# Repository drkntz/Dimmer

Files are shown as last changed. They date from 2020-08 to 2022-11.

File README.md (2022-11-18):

# Dimmer
A peripheral for microprocessor control of 120V AC.

This project originally started in 2020 as a proof of concept for an AC motor controller, but can be used for many projects involving variable duty cycle AC control. It supports operation for low current (<5A) AC driving as a low-side switch. 

The original board included both an AC triac control and a 5V non-isolated power supply (linkswitch LNK3206). This unit was meant for use in situations where the device is fully enclosed in an insulated housing. However, if fully isolated operation is desired, the Dimmer may be used with an external 5V power supply, as it contains optically isolated triac drive and zero-crossing detection circuits.

The software in this project was used for a raspberry pi to connect with the rev1 board. 

TODO: Schematic printout needs some work, is missing interface header J1. Rev2 will fix this.

# Schematic rev 1
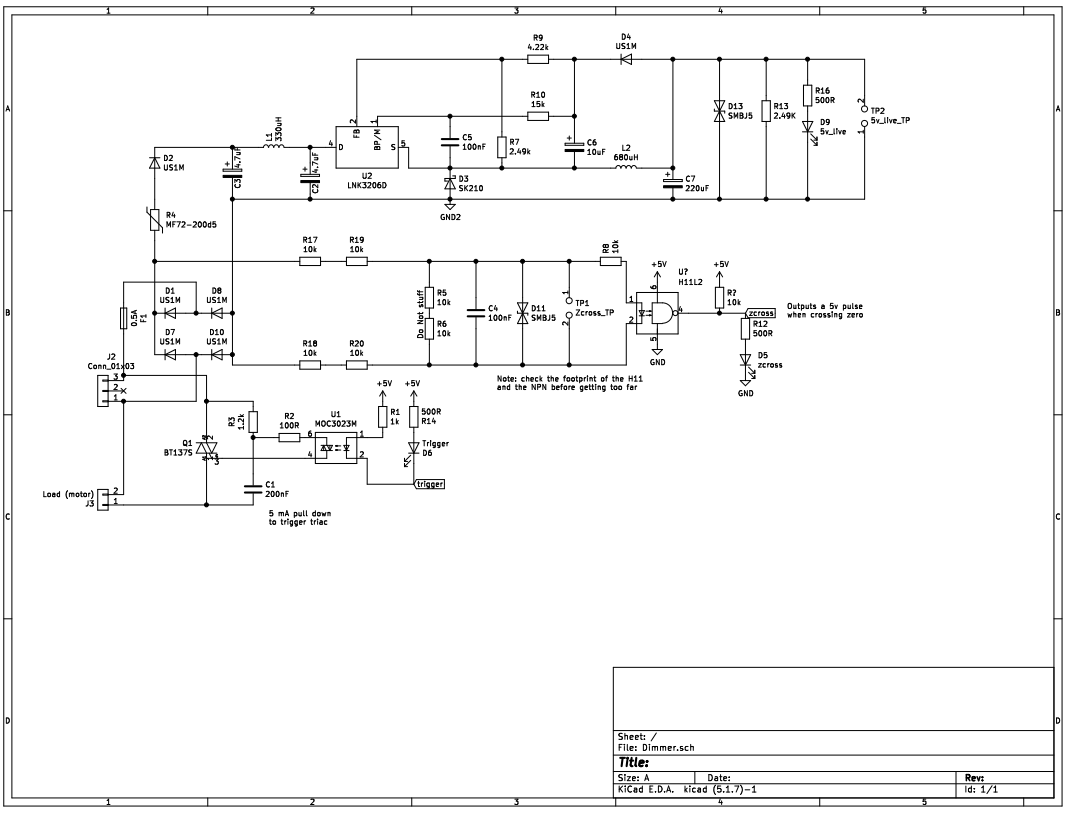
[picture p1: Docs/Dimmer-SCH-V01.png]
SCH


# PCB Layout rev 1
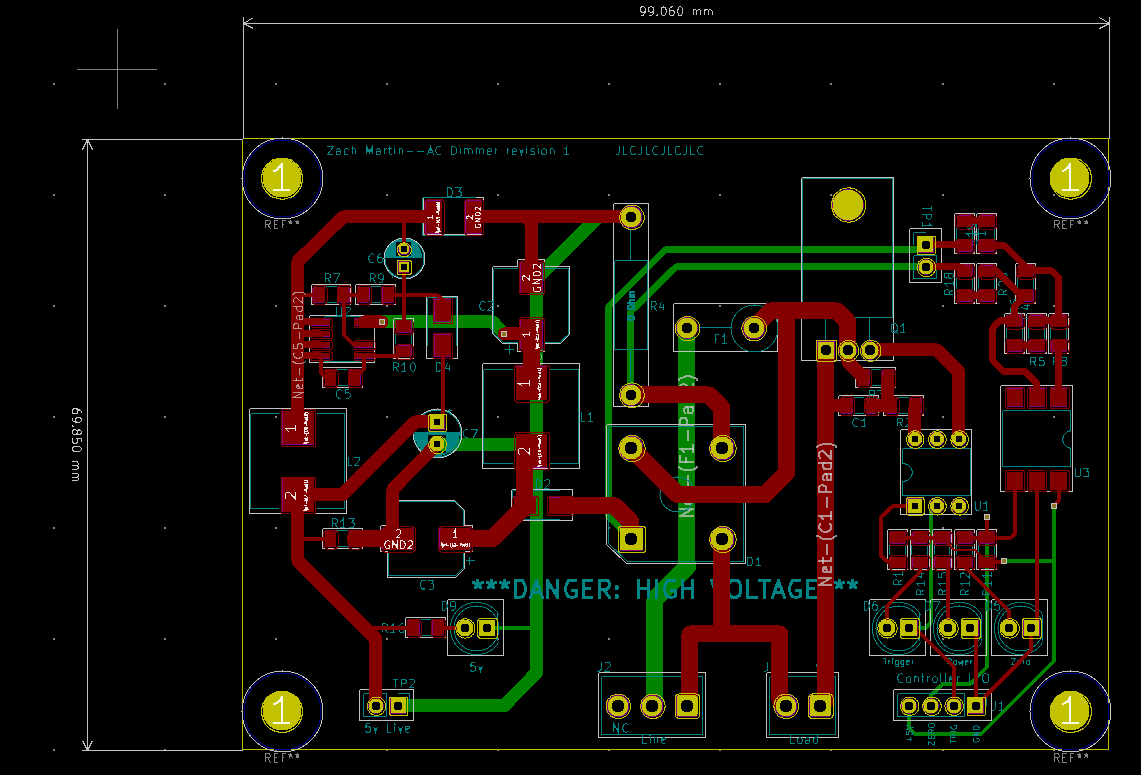
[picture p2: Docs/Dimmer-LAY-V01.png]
LAY


# PCB 3-D Model rev 1
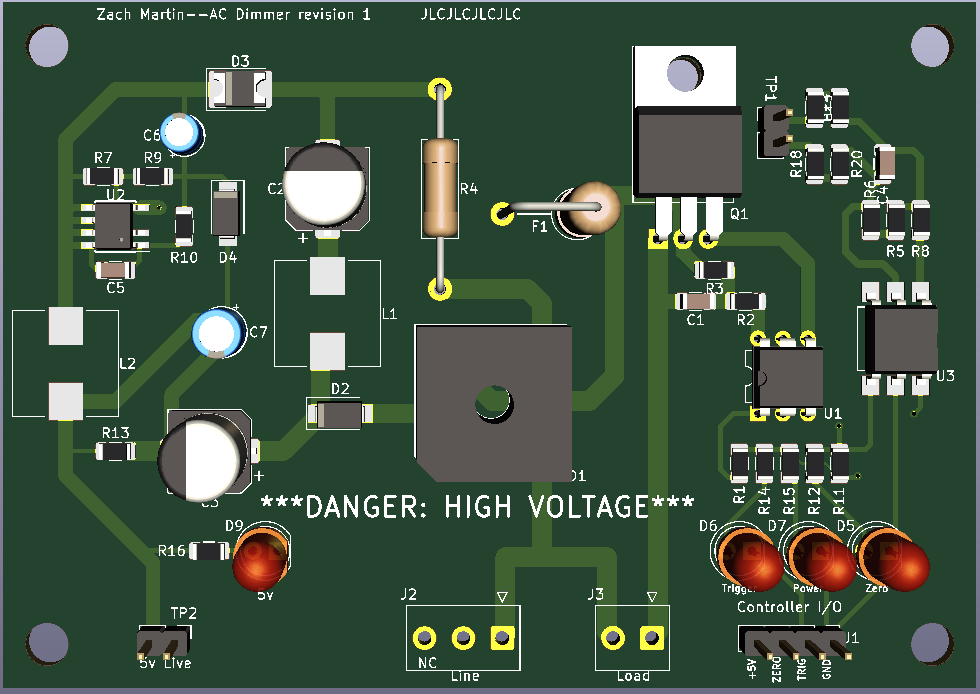
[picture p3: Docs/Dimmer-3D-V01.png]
3D


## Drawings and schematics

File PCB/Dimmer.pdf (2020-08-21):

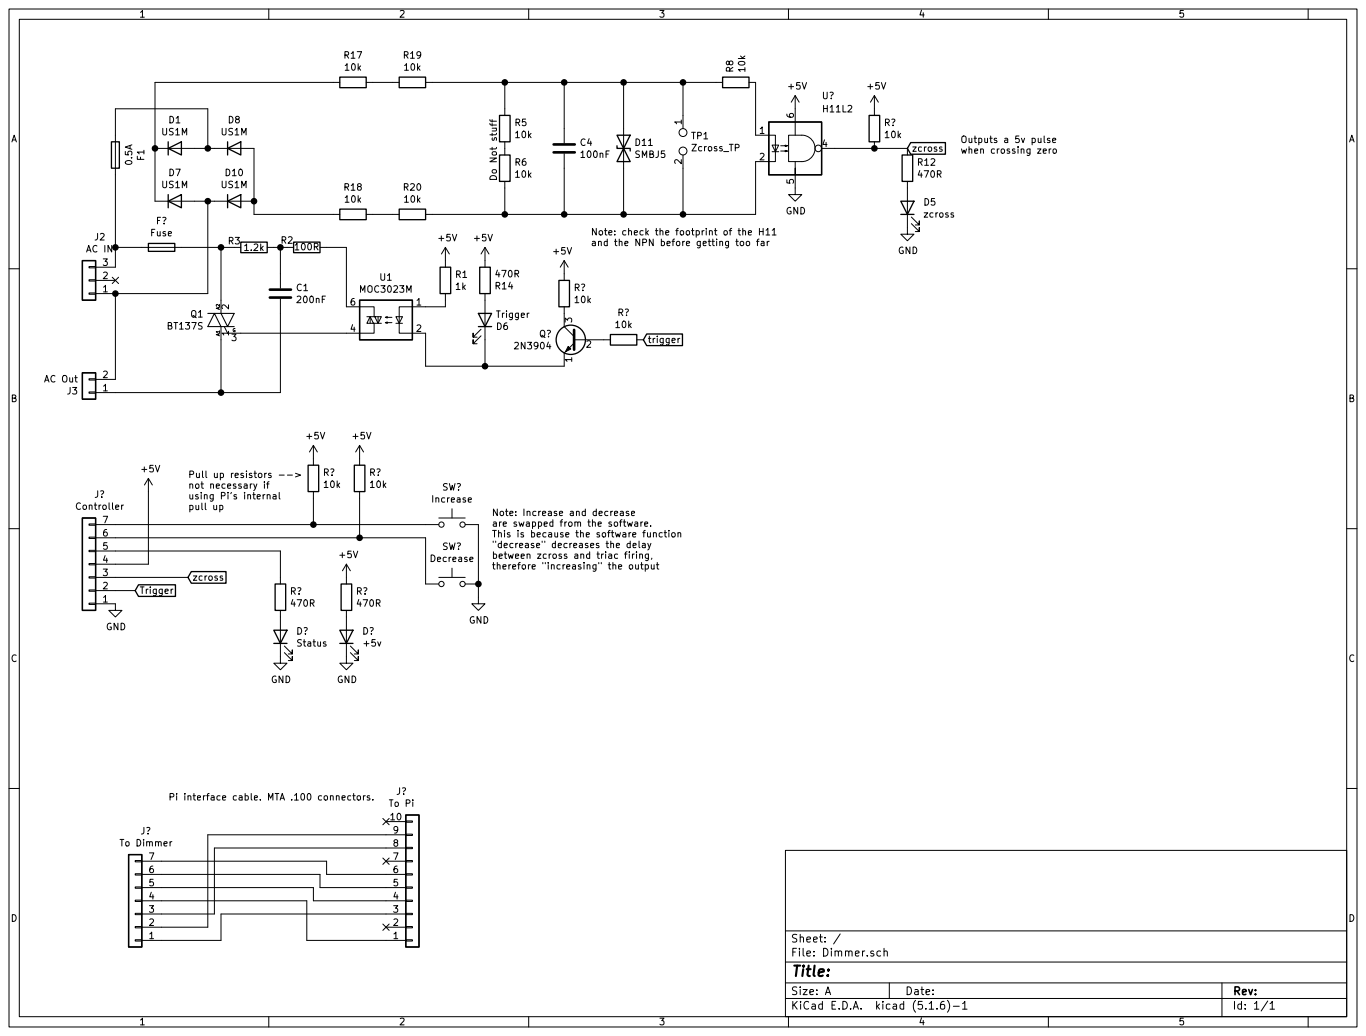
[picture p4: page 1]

Note: check the footprint of the H11
and the NPN before getting too far

are swapped from the software. This is because the software function

"decrease" decreases the delay
between zcross and triac firing,
therefore "increasing" the output

Id: 1/1 Title: File: Dimmer.sch Sheet: /

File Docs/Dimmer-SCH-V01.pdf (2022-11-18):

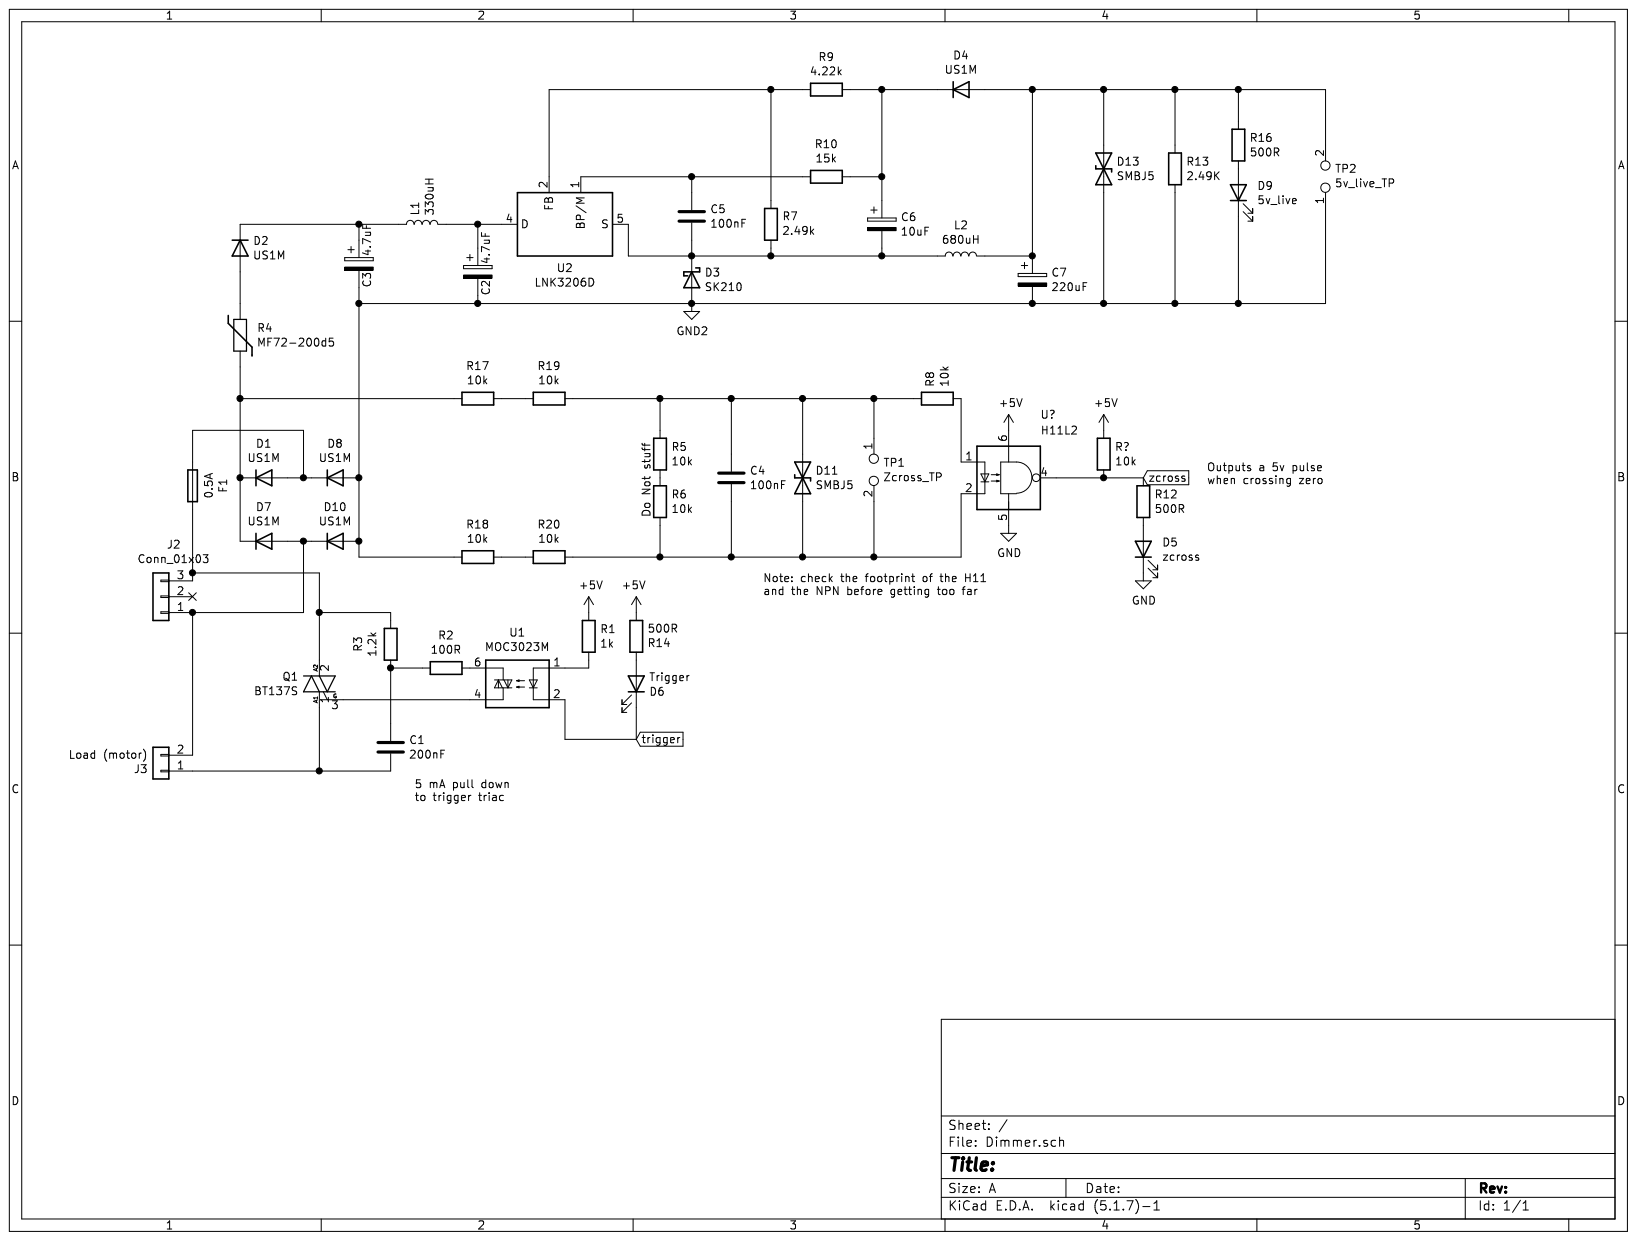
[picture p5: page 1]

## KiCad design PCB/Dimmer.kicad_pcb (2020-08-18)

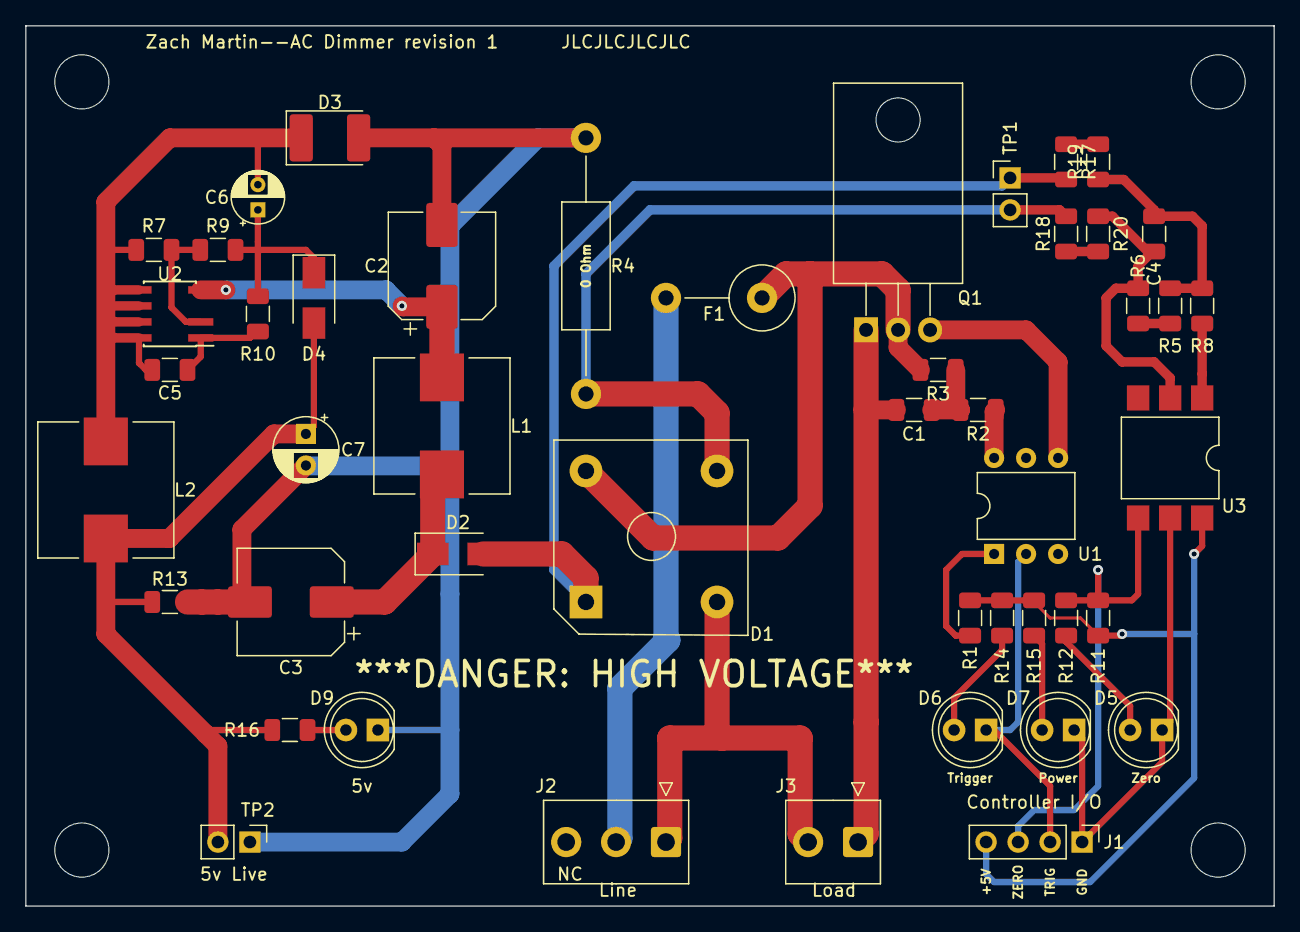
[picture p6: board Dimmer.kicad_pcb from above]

Board: 2 copper layers, 99.1 x 69.8 mm, 47 parts (0 on the bottom side), 32 nets.

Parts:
C1: 200nF; C_1206_3216Metric
C2, C3: 4.7uF; CP_Elec_8x10
C4: 10nF; C_1206_3216Metric
C5: 100nF; C_1206_3216Metric
C6: 10uF; CP_Radial_D4.0mm_P2.00mm
C7: 100uF; CP_Radial_D5.0mm_P2.50mm
D1: D_Bridge_+A-A; Diode_Bridge_Vishay_KBPC6
D2, D4: US1M; D_SMA
D3: SK510; D_2114_3652Metric_Pad1.85x3.75mm_HandSolder
D5: zcross; LED_D5.0mm
D6: Trigger; LED_D5.0mm
D7: EXT_PWR; LED_D5.0mm
D9: 5v_live; LED_D5.0mm
F1: 2A; R_Axial_DIN0516_L15.5mm_D5.0mm_P7.62mm_Vertical
J1: Conn_01x04; PinHeader_1x04_P2.54mm_Vertical
J2: Conn_01x03; TE_826576-3_1x03_P3.96mm_Vertical
J3: Load (motor); TE_826576-2_1x02_P3.96mm_Vertical
L1: 560uH; L_Wuerth_HCI-1030
L2: 680uH; L_Wuerth_HCI-1030
Q1: SC146D; TO-220-3_Horizontal_TabDown
R1, R11, R13: 1k; R_1206_3216Metric
R2: 100R; R_1206_3216Metric
R3: 1.2k; R_1206_3216Metric
R4: 8R; R_Axial_DIN0411_L9.9mm_D3.6mm_P20.32mm_Horizontal
R5, R6, R8, R17, R18, R19, R20: 10k; R_1206_3216Metric
R7: 2.49k; R_1206_3216Metric
R9: 4.22k; R_1206_3216Metric
R10: 15k; R_1206_3216Metric
R12, R14, R15, R16: 500R; R_1206_3216Metric
TP1: Zcross_TP; PinHeader_1x02_P2.54mm_Vertical
TP2: 5v_live_TP; PinHeader_1x02_P2.54mm_Vertical
U1: MOC3023M; DIP-6_W7.62mm
U2: LNK3206D; PowerIntegrations_SO-8C
U3: H11L1; SMDIP-6_W9.53mm

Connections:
+5V: J1.4, R1.1, R11.2, R14.2, R15.2, U3.6
GND: D5.1, D7.1, J1.1, U3.5
GND2: C2.2, C3.2, C7.2, D3.2, D9.1, R4.1, R13.2, TP2.1
unnamed: C1.1, R2.1, R3.2
unnamed: C1.2, J3.1, Q1.1
unnamed: C2.1, L1.1, U2.4
unnamed: C3.1, D2.1, L1.2
unnamed: C4.1, R5.1, R8.1, R19.1
unnamed: C4.2, R6.2, R20.1, U3.2
unnamed: C5.1, R10.2, U2.1
unnamed: C5.2, C6.2, D3.1, L2.1, R7.1, U2.5, U2.6, U2.7, U2.8
unnamed: C6.1, D4.1, R9.1, R10.1
unnamed: C7.1, D4.2, L2.2, R13.1, R16.1, TP2.2
unnamed: D1.1, D2.2, R17.2, TP1.1
unnamed: D1.2, J2.1, J3.2
unnamed: D1.3, R4.2, R18.2, TP1.2
unnamed: D1.4, F1.1, Q1.2, R3.1
unnamed: D5.2, R12.2
unnamed: D6.2, R14.1
unnamed: D7.2, R15.1
unnamed: D9.2, R16.2
unnamed: F1.2, J2.2
unnamed: Q1.3, U1.4
unnamed: R1.2, U1.1
unnamed: R2.2, U1.6
unnamed: R5.2, R6.1
unnamed: R7.2, R9.2, U2.2
unnamed: R8.2, U3.1
unnamed: R17.1, R19.2
unnamed: R18.1, R20.2
trigger: D6.1, J1.2, U1.2
zcross: J1.3, R11.1, R12.1, U3.4

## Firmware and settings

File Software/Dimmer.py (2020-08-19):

# Dimmer.py
# This is a program which controls the firing of a triac from the GPIO pins of a raspberry Pi
# Created by Zach Martin on 28 Jul 2020
# 

import RPi.GPIO as GPIO
import time 
from Settings import *	# Settings file for this program. Notably, dimmerProfile defines which ramp up profile is used

GPIO.setmode(GPIO.BCM) # Uses the BCM pin definitions

##### Names for BCM GPIO pins
POWER = 14 	# Power LED
INC = 15 	# Increase delay
DEC = 18 	# Decrease delay
ZCROSS = 23	# Zero crossing input pin
TRIG = 24	# Triac trigger output pin

##### Initialize interfaces
GPIO.setup(POWER, GPIO.OUT)
GPIO.setup(INC, GPIO.IN, pull_up_down=GPIO.PUD_UP) # Note: Pulled up internally
GPIO.setup(DEC, GPIO.IN, pull_up_down=GPIO.PUD_UP) # Note: Pulled up internally
GPIO.setup(ZCROSS, GPIO.IN)
GPIO.setup(TRIG, GPIO.OUT)
GPIO.output(TRIG, GPIO.LOW) # Initializes the triac as LOW/off (High, because of the external NPN inverter)

##### Global-scope "constants"
# Timing values are in microseconds
MINDELAY = 1000	# Minimum delay between zcrossing and firing
MAXDELAY = 6500 # Max delay. Output is held low/off when at MAXDELAY
PULSE = 500 	# Length of trigger pulse
STEPSIZE = 250	# Size of timing variation steps. 
STEPLIGHT = 100 # Size of timing steps for the light bulb profile
MOTORMIN = 5750 # Minimum delay for the motor dimmer profile
NUMSTEPS = 5 # Number of steps in the motor ramp up
STEPS90 = 10 # Number of steps till roughly 90v as measured on an RMS voltmeter
	
##### Global-scope variables
ledOn = 0	
delay = MAXDELAY


def zeroCross(channel):	# Interrupt handler for the positive-going zero crossing signal. Drives the triac.
	if(delay != MAXDELAY):
		time.sleep(delay/1000000)
		GPIO.output(TRIG, GPIO.HIGH)
		time.sleep(PULSE/1000000)
		GPIO.output(TRIG, GPIO.LOW)


def blink(condition):	# Status LED toggler or direct control via 0, 1, 2; or via False, True, and 2. 
	global ledOn
	if(condition == 2 and ledOn):
		blink(False)
	elif(condition):
		GPIO.output(POWER, GPIO.HIGH) # Turns on power LED on to indicate script is running. 3.3v max 16mA
		ledOn = 1
	elif(not condition):
		GPIO.output(POWER, GPIO.LOW) # Turns off power LED
		ledOn = 0
	else:
		blink(True)


def getSpeed(ramp):	# Controls the delay that the zero cross handler uses to do its thing.
	global delay
	global numTrigs
	blink(2)

	# Custom dimmer profiles
	if(ramp==4):	# Ramp up to 90v RMS.
		print('90v ramp enabled')
		numSteps = STEPS90
		ramp = 1
	else:
		numSteps = NUMSTEPS
	if(ramp==1):	# Ramp up numSteps steps. TODO: ramp up to a specific delay instead of # of steps.
		print('Motor Ramp Enabled')
		#delay = 5700
		#time.sleep(0.2)
		#delay = MAXDELAY - STEPSIZE
		for i in range(numSteps):
			time.sleep(0.5)
			delay -= STEPSIZE
			print('Delay:', delay, '\r', end='')
			blink(2)
		time.sleep(10)
	elif(ramp==2):	# Ramp up to the minimum delay
		print('Full Range Ramp Enabled')
		while(delay > MINDELAY):
			time.sleep(0.5)
			delay -= STEPSIZE
			print('Delay:', delay, '\r', end='')
			blink(2)
		time.sleep(10)
	elif(ramp==3):	# Ramp up to the brightest of a 40w bulb
		print('Light Bulb Ramp Enabled')
		while(delay > MINDELAY):
			time.sleep(0.1)
			delay -= STEPLIGHT
			print('Delay:', delay, '\r', end='')
			blink(2)
		time.sleep(10)
	delay = MAXDELAY
	print('Manual Mode started')
	print('Delay:', delay, '\r', end='')
	while(True):	# Main running loop. Blinks LED and polls for input
		blink(2)
		if(not GPIO.input(DEC) and delay > MINDELAY):
			delay -= STEPSIZE
			print('Delay:', delay, '\r', end='')
			time.sleep(0.4)
		elif(not GPIO.input(INC) and delay < MAXDELAY):
			delay += STEPSIZE
			print('Delay:', delay, '\r', end='')
			time.sleep(0.4)
		else:
			time.sleep(0.1)


def main():	# Main function
	getSpeed(dimmerProfile)
	while(True):
		blink(2)
		time.sleep(0.1)


if __name__ == '__main__':
	GPIO.add_event_detect(ZCROSS, GPIO.RISING, callback=zeroCross, bouncetime=3) # Setup for GPIO interrupt. Debounce is in milliseconds
	main()	

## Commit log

2020-08-18 Initial commit 18 Aug 2020 ZM
    [CARIceCreamControl-B_Cu.gbr, CARIceCreamControl-B_Mask.gbr, CARIceCreamControl-B_Paste.gbr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]
2020-08-18 Updating software version to version containing interrupt handlers instead of polling and messy multithreading.
2020-08-18 Removed backup software, changed schematic to improve circuit. No change on PCB.
    [Dimmer.sch]
2020-08-19 Updated schematic, software to clarify speed buttons
    [Dimmer.sch]
2020-09-30 Latest version before switching PCs
    [Dimmer.sch]
2022-01-20 Migrating from personal gitserver
    [Dimmer.kicad_pcb, Dimmer.sch]
2022-01-20 re-organize file structure
    [CARIceCreamControl-B_Cu.gbr, CARIceCreamControl-B_Mask.gbr, CARIceCreamControl-B_Paste.gbr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]
